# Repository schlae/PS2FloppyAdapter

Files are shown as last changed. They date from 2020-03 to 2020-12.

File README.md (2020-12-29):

# PS/2 Floppy Adapter

This PS/2 floppy adapter is designed to allow standard PC floppy drives to be
used in IBM PS/2 systems that have 40-pin edge connectors for their floppy
drive interfaces. This can be quite useful because many PS/2 floppy drives have failed due to leaking capacitors or mechanical problems, and can be difficult or impossible to repair.

Compatible models include

* IBM PS/2 Model 50 and 50Z
* IBM PS/2 Model 70

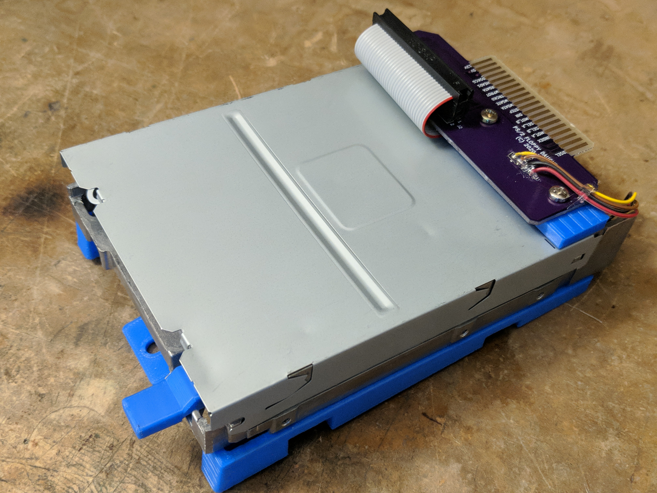
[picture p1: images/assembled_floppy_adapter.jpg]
Photo of floppy drive with adapter hardware mounted


Here's what the adapter looks like when installed in a Model 50Z.

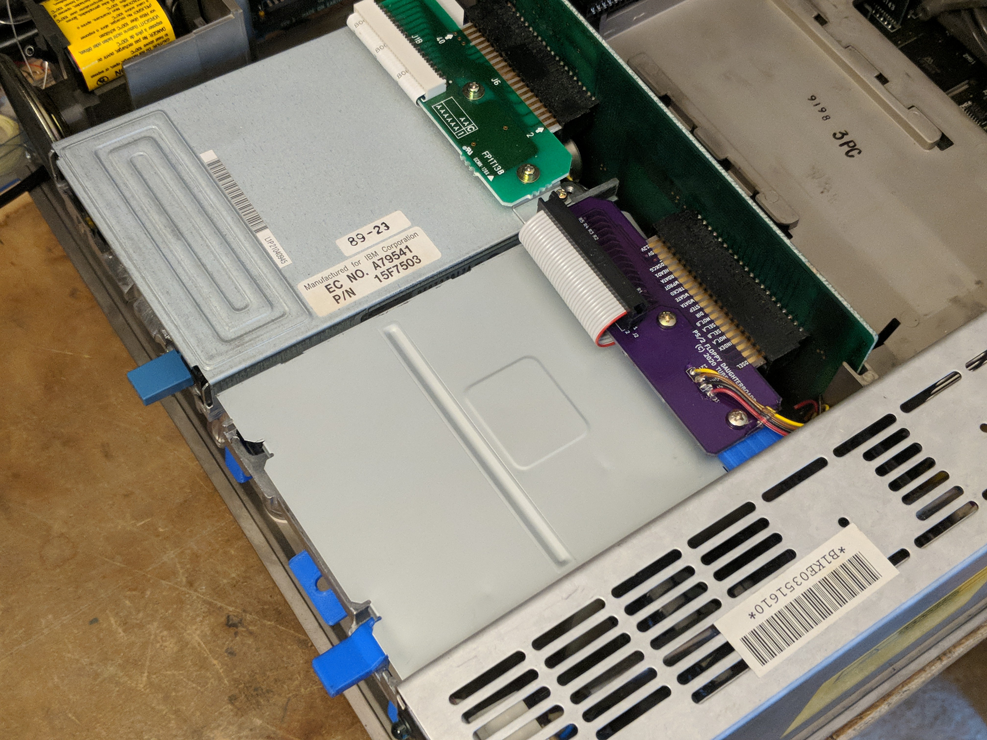
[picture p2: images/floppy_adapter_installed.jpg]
Photo of floppy drive with adapter installed in a computer


## Connector PC Board

There are several pieces to the design. First, there is a circuit board: the design files are here.

[Schematic](https://github.com/schlae/PS2FloppyAdapter/blob/master/PS2FloppyAdapter.pdf)

[Fab Files](https://github.com/schlae/PS2FloppyAdapter/blob/master/cam/PS2FloppyDaughterboardRevA.zip)

The bill of materials is as follows:

| Designator | Quantity | Description |
| ---  | --- | --- |
| J2  | 1 | 34-pin 0.1" breakaway header |
| R1-R5 | 5 | 1K ohm resistors, 0603 |

Note that R1-R5 can be either 1% or 5% since the exact value is not critical.

J3 provides power to the PC floppy drive. One way to build it is to cut off
a 0.1" power header from an old PC power supply, Y splitter, or similar
adapter, and then solder the wires to the appropriate connections on the
adapter board. Black to ground, red to +5V, and yellow to +12V.

You'll also need a short length of 34-pin ribbon cable with a male IDC connector crimped onto each end. This connects the adapter board to the floppy drive.

## Mechanical Parts

Several parts mechanically adapt the standard PC floppy drive to fit in the
PS/2. Each of them can be printed on a commodity FDM 3D printer.

[Drive Sled](https://github.com/schlae/PS2FloppyAdapter/blob/master/mech/PS2_50_floppy_sled_15F7502.STL) - This is compatible with IBM FRU 15F7502. 

[Plugboard](https://github.com/schlae/PS2FloppyAdapter/blob/master/mech/PS2_50_floppy_plugboard.STL) - The plugboard sits between the floppy drive and the connector PC board, holding it at just the right angle.

[Eject button (Sony MPF920)](https://github.com/schlae/PS2FloppyAdapter/blob/master/mech/PS2_50_floppy_button_sony_mpf920.STL) - Eject button for the Sony MPF920 floppy drive

[Eject button (Teac FD235HF)](https://github.com/schlae/PS2FloppyAdapter/blob/master/mech/PS2_50_floppy_button_teac_fd235HF.STL) - Eject button for the Teac FD235HF floppy drive

The STL files are oriented in the optimal orientations for printing. The sled has some overhangs and will require supports to be added in order to print correctly.

* Two M3-0.5mm, 5mm long self tapping screws. These attach the PCB to the plugboard.

* Four M3-0.5mm, 10mm long machine screws. These attach the floppy drive to the sled.

## Assembly

Remove the old floppy drive bezel. The exact way to do this varies depending on the drive, but typically there are plastic tabs on the sides that clip into the drive. On some drives you may have to remove the metal lid to get at them.

Remove the old eject button from the floppy drive. The Sony drive button simply slides up. You might have to rock it back and forth a bit. The Teac drive button is harder to remove; if you get in with a dental pick or screwdriver, pull up the plastic catch and the button should slide straight out.

Install the new eject button just like you removed the old one but in reverse. If it refuses to go in, don't force it. There are some fairly detailed features that may require cleanup with a sharp knife in order for it to fit.

Before installing the drive on the sled, take the sled and heat the plastic locking tab in the front with a hair dryer or heat gun (low heat) and bend it down. It needs to bend down far enough to engage with a slot in the PS/2 chassis which locks it in place when it is installed.

Then, using the 10mm machine screws, install the drive on the sled. The floppy drive slot should face the same direction as the locking tab on the sled.

Install the PC board on the plastic plugboard using the two self-tapping screws. You can temporarily tape it in place to figure out how long the 34-pin IDC cable and the drive power cable need to be.

Now slide the assembly into your PS/2 computer and plug the PC board into the slot at the back of the drive bay. The plugboard should rest on the top of the floppy drive. Make a mark so you know exactly where it should go. Then remove the assembly and glue the plugboard to the top of the floppy drive, right where you placed your mark. You can try using double-sided tape, but 3M VHB (Very High Bond) is probably the most secure.

I've found that the drive LED lines up fairly well with the LED window on the stock PS/2 drive bezel (IBM FRU 15F7534).

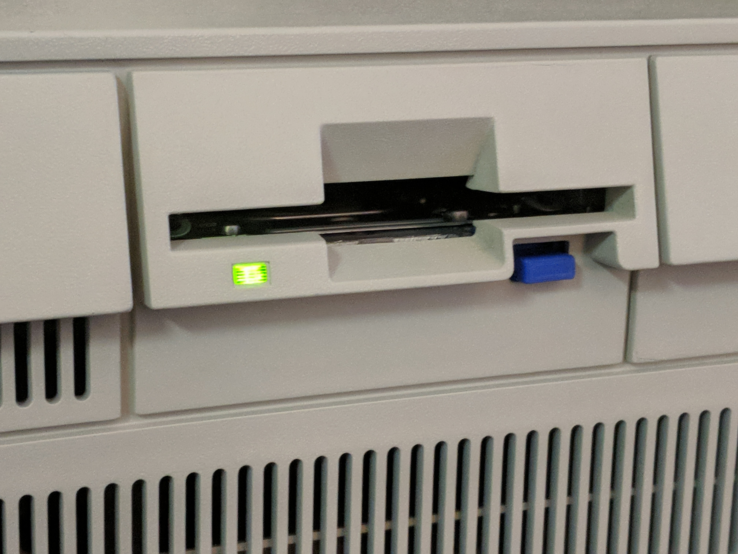
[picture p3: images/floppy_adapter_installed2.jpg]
Photo of the assembly installed in the PS/2


There is a variant of the drive bezel, FRU 62X0362, which has the LED above the drive slot, which won't work. You'll need to run a wire and hot glue the LED on top of the floppy drive or print a replacement bezel (see below).

## Optional Parts

I've also made a 3D-printable model of the PS/2 Model 50/50Z drive bezel if you want to install this drive as a second floppy drive, or if your machine was missing it.

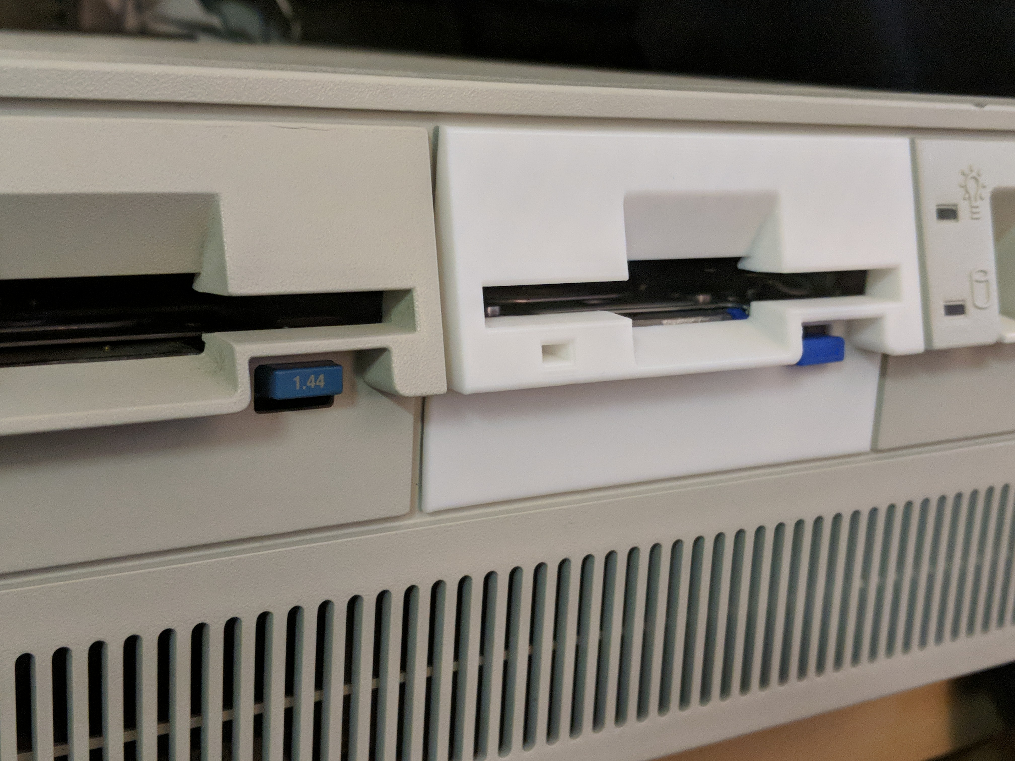
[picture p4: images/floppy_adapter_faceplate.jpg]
Photo of the 3D-printed drive bezel installed in the PS/2


This part is tricky to print and requires support structures. It is printed on the side so that the front panel texture will look reasonable, and also so that the plastic locking tabs will be sturdy. Use pliers and side cutters to remove the support structure, and be sure to wear safety glasses!

## Archive

Here is the old version of the floppy adapter PC board. This can be used to electrically connect a floppy drive to the IBM 40-pin connector used on some additional models, such as the Model 60 and 80. There is no mechanical mounting design for these models yet.

[Fab Files](https://github.com/schlae/PS2FloppyAdapter/blob/master/cam/PS2FloppyAdapterRevA.zip)

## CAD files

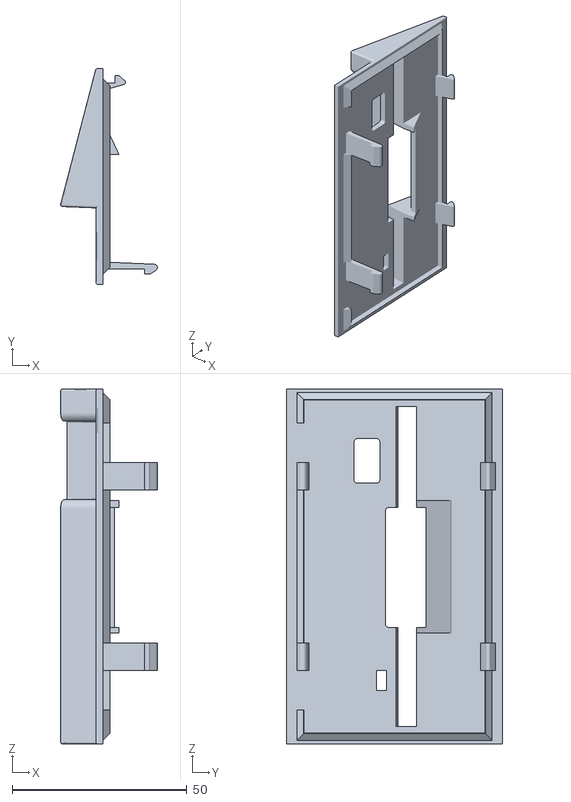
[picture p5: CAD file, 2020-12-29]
mech/PS2_50_floppy_front_panel.STL
27.7 x 62.0 x 101.7

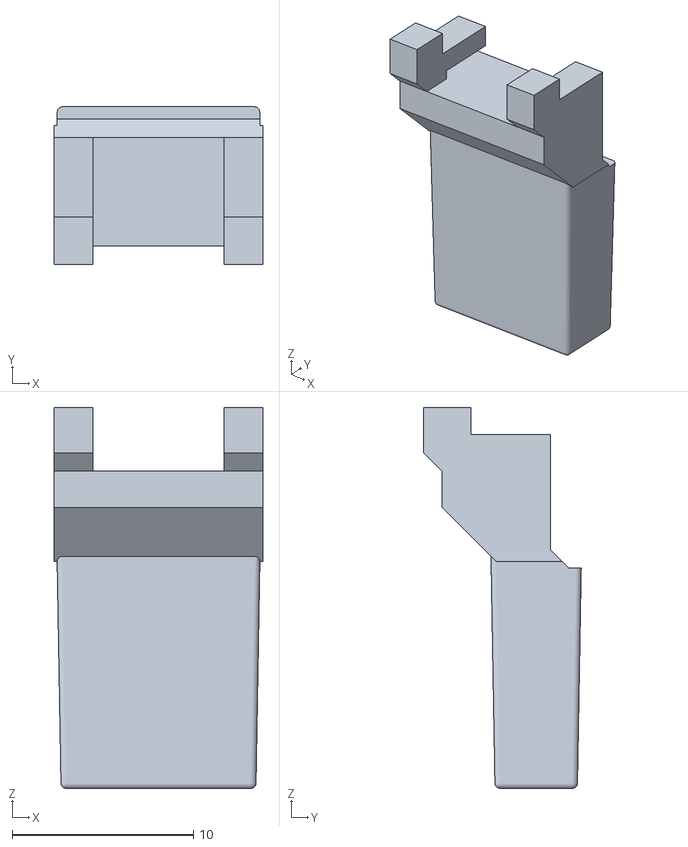
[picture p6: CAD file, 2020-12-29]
mech/PS2_50_floppy_button_teac_fd235HF.STL
11.5 x 8.68 x 21.0

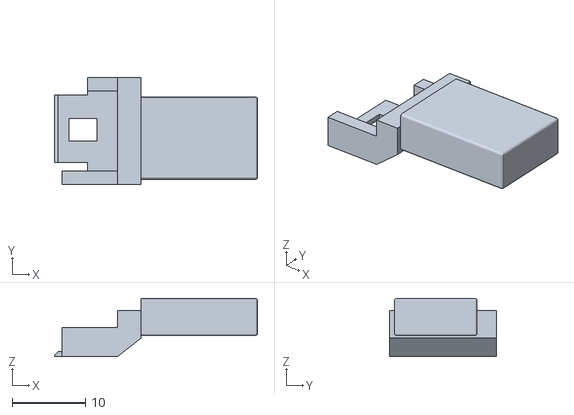
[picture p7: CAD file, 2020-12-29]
mech/PS2_50_floppy_button_sony_mpf920.STL
27.8 x 14.6 x 7.97

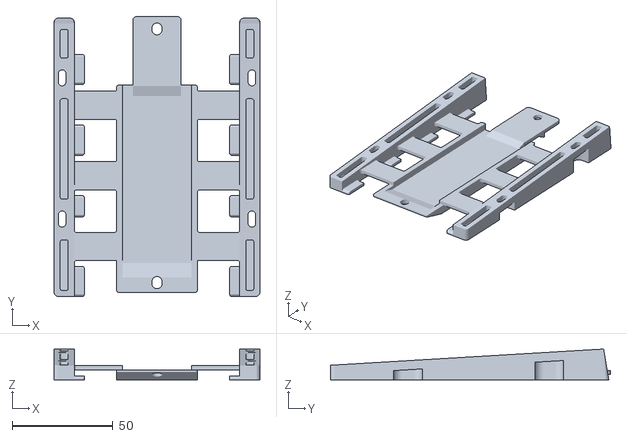
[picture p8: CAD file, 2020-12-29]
mech/PS2_50_floppy_sled_15F7502.STL
102.0 x 138.8 x 15.3

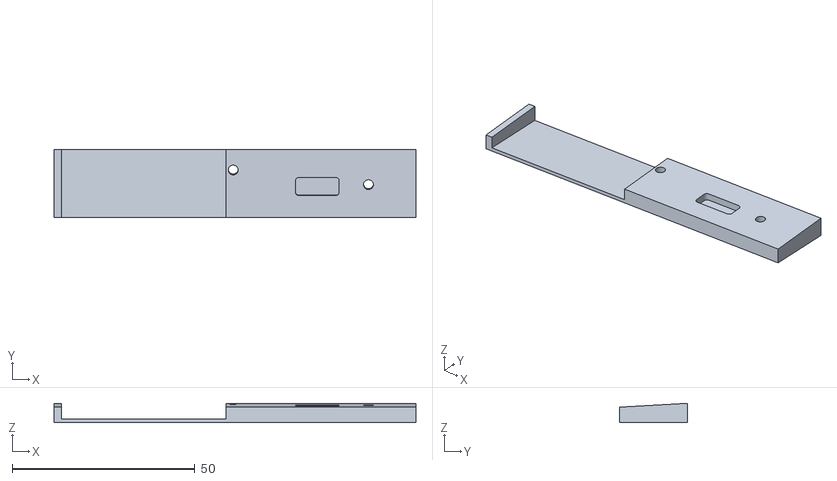
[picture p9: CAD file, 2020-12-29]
mech/PS2_50_floppy_plugboard.STL
99.0 x 18.6 x 5.30

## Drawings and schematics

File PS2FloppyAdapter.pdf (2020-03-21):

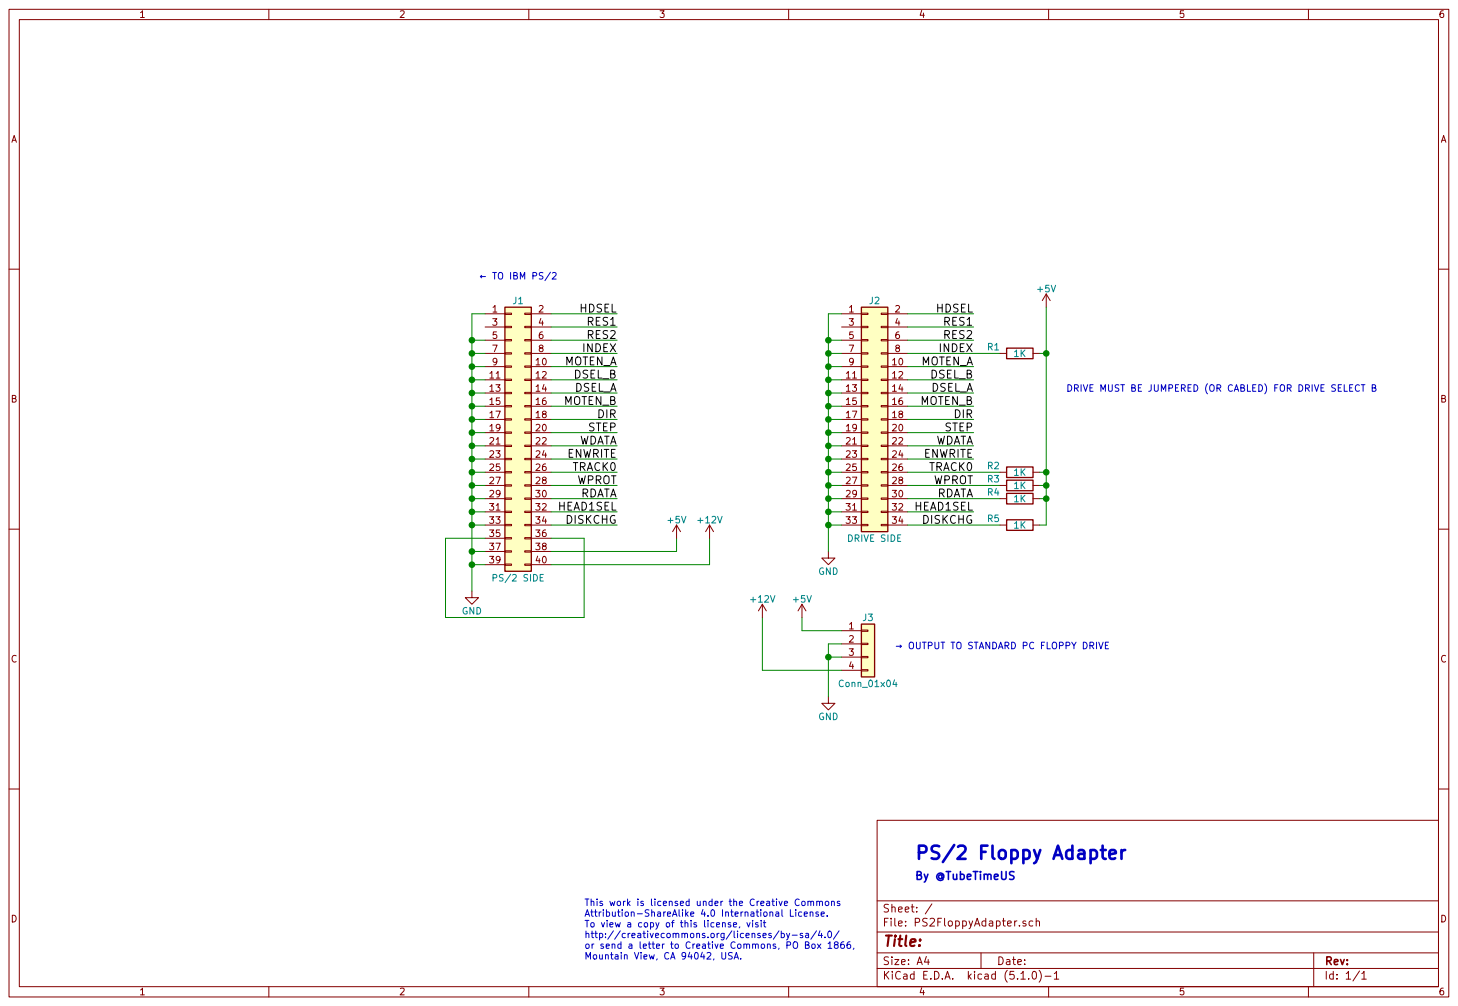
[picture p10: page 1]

35 | | 36
37 | | 38
39 | | 40

OUTPUT TO STANDARD PC FLOPPY DRIVE

This work is licensed under the Creative Commons Attribution-ShareAlike 4.0 International License. To view a copy of this license, visit

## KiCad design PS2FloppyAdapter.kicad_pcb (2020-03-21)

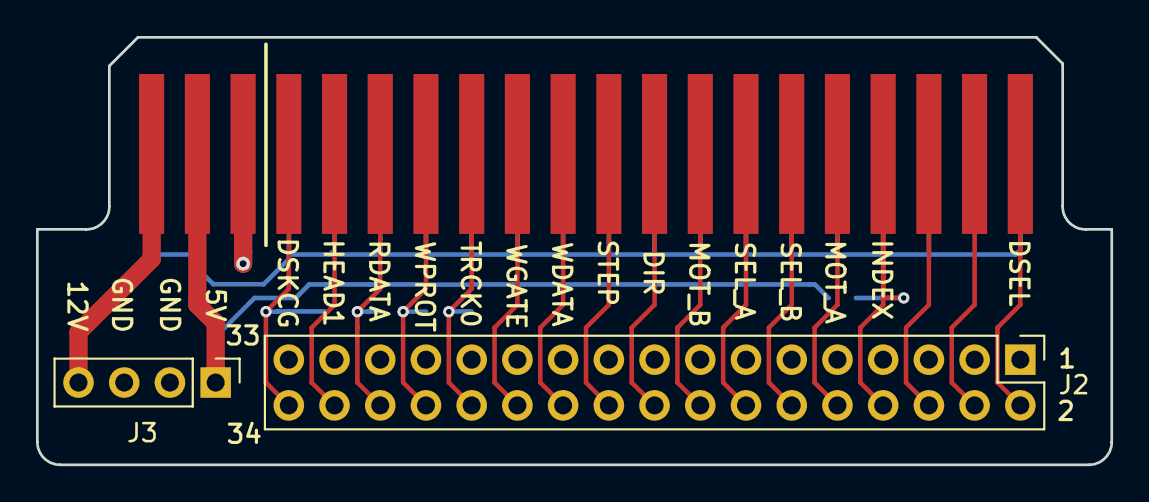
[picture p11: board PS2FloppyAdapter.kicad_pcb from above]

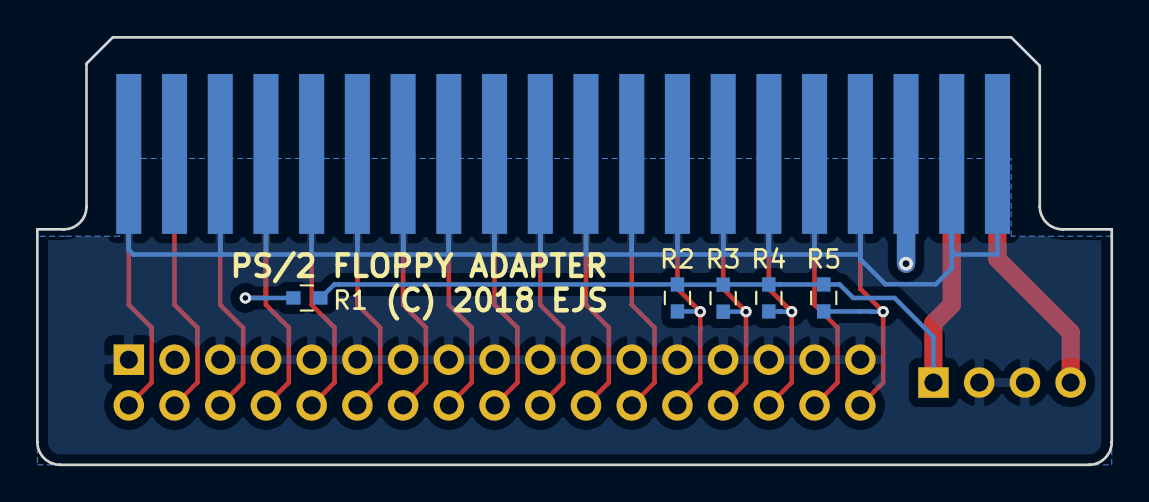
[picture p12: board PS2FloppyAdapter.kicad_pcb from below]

Board: 2 copper layers, 59.7 x 23.7 mm, 8 parts (5 on the bottom side), 21 nets.

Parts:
J1: Conn_02x20_Odd_Even; EDGE_FLOPPY40
J2: Conn_02x17_Odd_Even; Pin_Header_Straight_2x17_Pitch2.54mm
J3: Conn_01x04; Pin_Header_Straight_1x04_Pitch2.54mm
R1, R2, R3, R4, R5: 1K; RESC1608X55

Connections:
+5V: J1.38, J3.1, R1.1, R2.1, R3.1, R4.1, R5.1
+12V: J1.40, J3.4
/DIR: J1.18, J2.18
/DISKCHG: J1.34, J2.34, R5.2
/DSEL_A: J1.14, J2.14
/DSEL_B: J1.12, J2.12
/ENWRITE: J1.24, J2.24
/HDSEL: J1.2, J2.2
/HEAD1SEL: J1.32, J2.32
/INDEX: J1.8, J2.8, R1.2
/MOTEN_A: J1.10, J2.10
/MOTEN_B: J1.16, J2.16
/RDATA: J1.30, J2.30, R4.2
/RES1: J1.4, J2.4
/RES2: J1.6, J2.6
/STEP: J1.20, J2.20
/TRACK0: J1.26, J2.26, R2.2
/WDATA: J1.22, J2.22
/WPROT: J1.28, J2.28, R3.2
GND: J1.1, J1.5, J1.7, J1.9, J1.11, J1.13, J1.15, J1.17, J1.19, J1.21, J1.23, J1.25, J1.27, J1.29, J1.31, J1.33, J1.37, J1.39, J2.1, J2.5, J2.7, J2.9, J2.11, J2.13, J2.15, J2.17, J2.19, J2.21, J2.23, J2.25, J2.27, J2.29, J2.31, J2.33, J3.2, J3.3
unnamed: J1.35, J1.36

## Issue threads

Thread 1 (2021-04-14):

Permanently connected resistor network should be gated

WBSTClarke, 2021-04-14:
Hi there,
it is my opinion that the resistor network being permanently connected to +5V may interfere with the co-existence of a real PS/2 floppy drive. If DS1 (DSEL_B) is used to gate the +5V supply (and/or common GND) then the resistor network will only be active when the adapter is actively selected (All IBM PS/2 drives respond as drive 1, due to the "twist").

Regards,
Tim "WBST" Clarke

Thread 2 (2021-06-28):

Vice versa: PS/2 floppy on PC

cyberluke, 2021-06-28:
Hi, I want to use PS/2 combo floppy (3.5'' + 5.25'') on PC. Is is possible with your project?

schlae, 2021-06-29:
Is this a standard combo floppy drive that you want to fit to a PS/2 system? It might work; this floppy adapter wires both drive select lines through, but it's not a combination I've tested.

TallisGharial, 2025-01-22:
I have an IBM 8530, Personal System/2 Model 30. It’s the Model 30 that is based on the Intel 8086 processor (and not the 80286). It has an 8-bit ISA bus with 3 expansion slots and 640KB RAM.

It’s the 8530-021 model with a 20 MB hard disk (sadly not working, but I use a Lo-tech ISA XT CF Adapter which works well) and a single diskette drive, which is broken. This disk drive uses the edge-connector or ‘planar’-style connector.

You say that your adapter is compatible with models that include BM PS/2 Model 50 and 50Z and IBM PS/2 Model 70. Do you think that it will work and 8086-based, ISA, PS/2? Do you have any experience of using it with an 8086-based PS/2, or know of anyone who succeeded in using it?

Thanks, Simon

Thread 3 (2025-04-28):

Model 60 & 80 40-Pin Cable

hlub69, 2025-04-28:
I am having a hard time sourcing a 40-pin to edge floppy cable for the model 60 & 80.  I saw your archive for those 2 models.  Do you have any suggestions or recommendations?  Thank you.

schlae, 2025-04-28:
Do you mean just the ribbon cable itself, the IDC connectors, or the cable's wiring diagram?

hlub69, 2025-04-29:
I need the ribbon cable.

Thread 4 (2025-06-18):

Only compatible with PS/2 microchannel systems?

TallisGharial, 2025-06-18:
Is this adapter only compatible with PS/2 microchannel systems?

Or will it work with an IBM 8530, Personal System/2 Model 30 that is based on the 8086 processor? The IBM 8530 has an 8-bit ISA bus with 3 expansion slots and 640KB RAM, and uses an edge connector floppy drive.

Thanks
Tallis

schlae, 2025-06-19:
It should work with the Model 30, the pin connections on the edge connector are the same.

Closed 2025-06-19.

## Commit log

2020-03-21 Initial version
    [PS2FloppyAdapter.kicad_pcb, PS2FloppyAdapter.sch]
2020-03-21 Add readme, update design files
    [PS2FloppyAdapter.kicad_pcb]
2020-12-29 Added new board and mechanical parts
    [PS2FloppyDaughterboard.kicad_pcb, PS2_50_floppy_button_sony_mpf920.STL, PS2_50_floppy_button_teac_fd235HF.STL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]

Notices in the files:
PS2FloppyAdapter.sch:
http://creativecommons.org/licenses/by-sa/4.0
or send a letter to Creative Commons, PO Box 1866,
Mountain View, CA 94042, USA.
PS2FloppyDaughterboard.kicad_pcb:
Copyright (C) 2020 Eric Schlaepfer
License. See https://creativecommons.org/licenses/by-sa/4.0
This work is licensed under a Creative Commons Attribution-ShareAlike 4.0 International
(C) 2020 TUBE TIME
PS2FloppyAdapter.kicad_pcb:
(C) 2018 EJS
